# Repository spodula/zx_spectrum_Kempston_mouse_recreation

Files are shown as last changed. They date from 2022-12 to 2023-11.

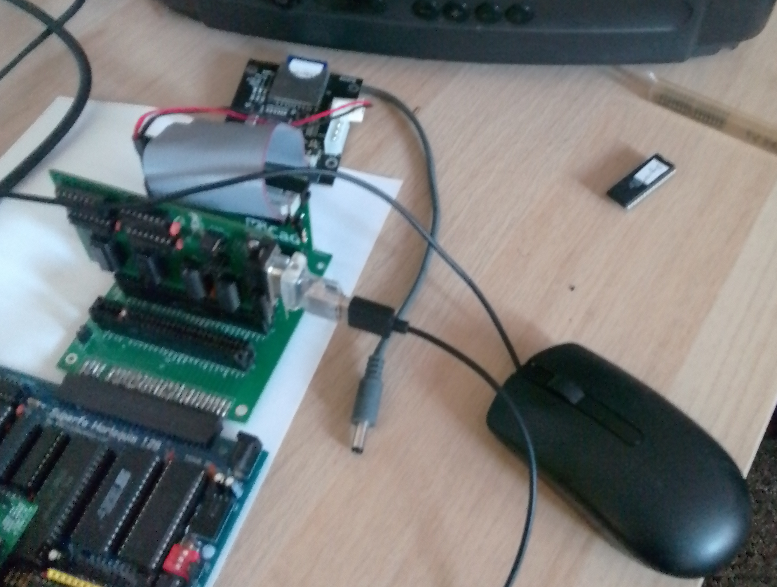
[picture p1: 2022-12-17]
mouse-board-in-use.jpg

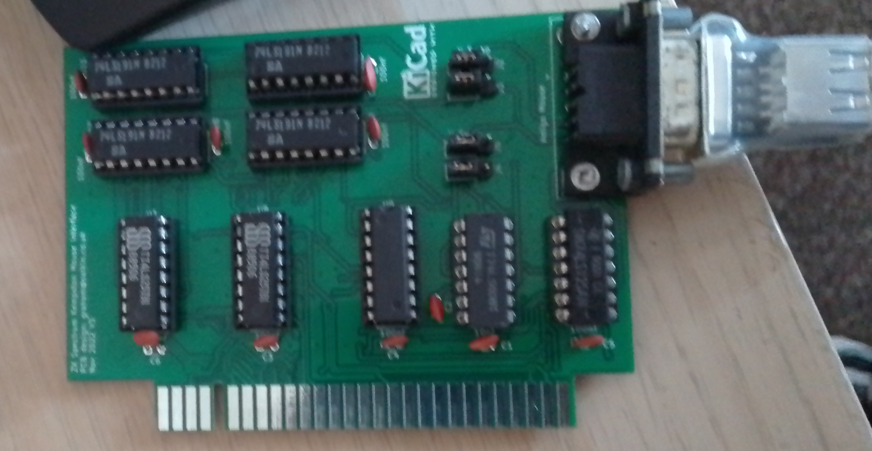
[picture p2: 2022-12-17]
mouse-board1.jpg

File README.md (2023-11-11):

# zx_spectrum_Kempston_mouse_recreation
This is a copy of the classic Kempston mouse interface re-designed to use Amiga mice.
it uses all the same components, just pinout of the mouse connector differs from the classic kempston mouse.
(So in the unlikely event you have an original kempston mouse, DO NOT plug it in)
I personally use an amiga Mouse adapter I got from Ebay with an old Dell Optical mouse. This seems to work fine. 

Gerbers files are complete, and you should just be able to zip them up and send them straight to your PCB manafacturer of your choice. 

All of this was done from the Schematics available at: 
Kio at https://k1.spdns.de/Vintage/Sinclair/82/Peripherals/Mouse%20Interfaces/Kempston%20Mouse%20Interface/
My additions are:
* support for 3 button mice
* Re-arrange pinout so its compatable with the Amiga mouse. 

BUGS!
-----
Minor bug, C1 should be next to C2, and C8 should be where C1 is for decoupling!
Fortunately, as the board is overly decoupled anyway (And frankly, its doubtful if U2 needs decoupling, as its only changes its logic states a few tens of times a second at most), this isnt really an issue, HOWEVER Do make sure you dont put a 100nf as C1. This could cause bad reads from the mouse. 

Parts required: 
---------------
* 74LS191 x4
* 74LS257 x2
* 74LS138
* 74LS00
* 74LS125
* 10nf capacitor x2
* 100nf capacitors x9
* PCB mount DB9 connector.
* Edge connector x1 (If required)

Note, the jumpers J2,3,4,5 are there because i wasnt sure of the X1/X2 Y1/Y2 order. 
Now i know, you can just jumper the squared pins off (technically Pins 2/3), so the next version probably wont have them. 
(look at the terrible photos in the folder)

No licence on this board, use it, manafacture it, sell it, fart in its general direction, have fun with it..
If you do modify it, be sure to credit Kio at the above URL.

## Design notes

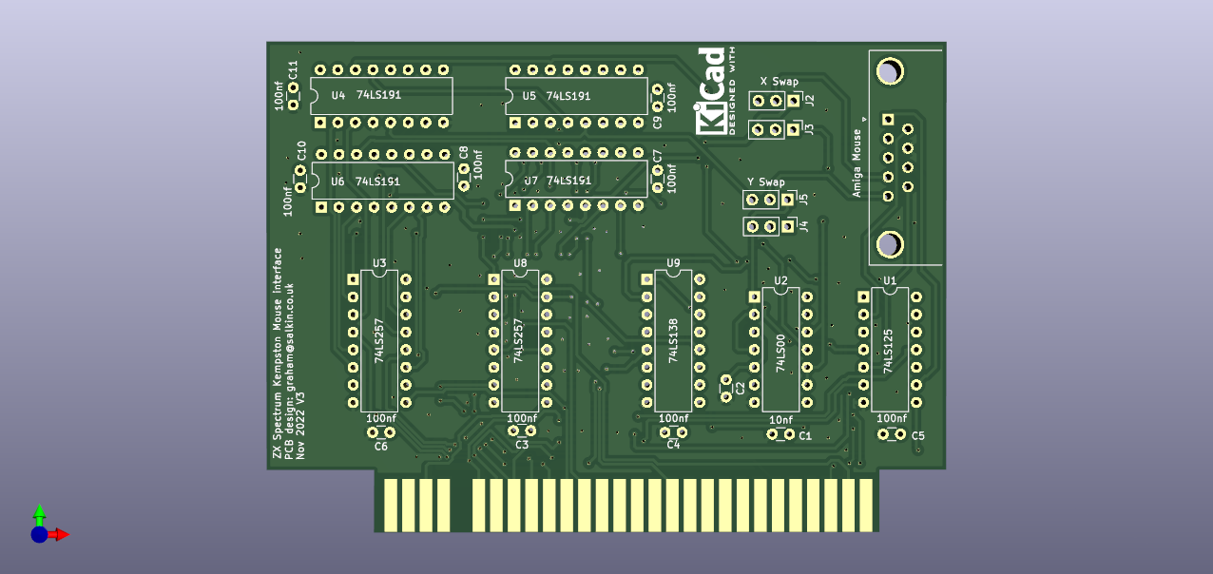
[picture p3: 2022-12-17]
Mouse_pcb_front.png

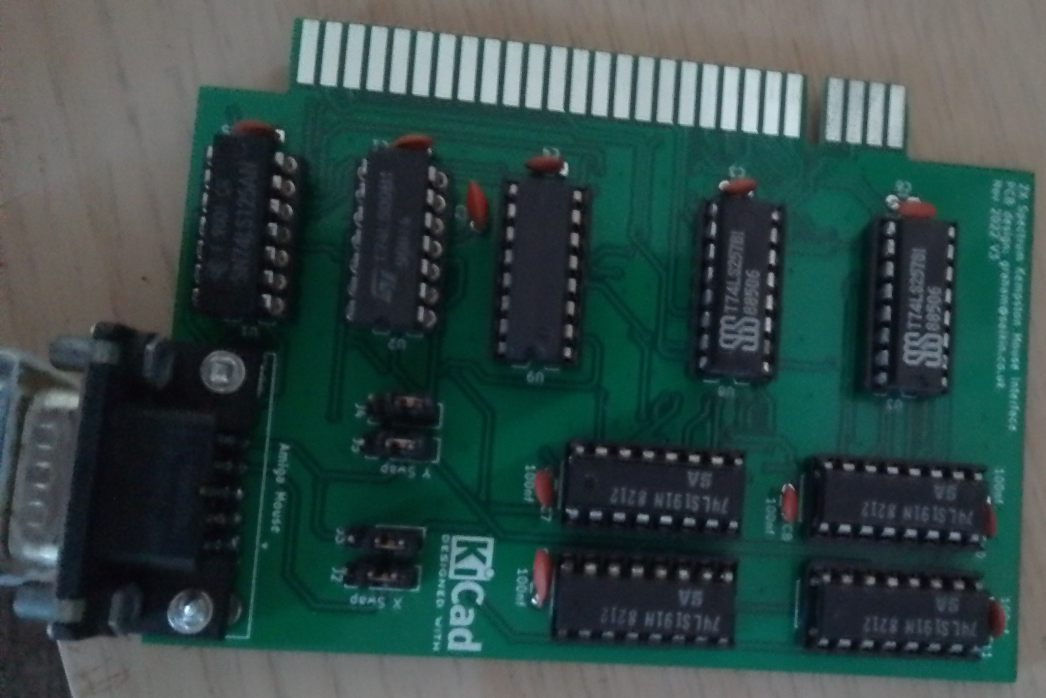
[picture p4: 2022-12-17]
mouse-board2.jpg

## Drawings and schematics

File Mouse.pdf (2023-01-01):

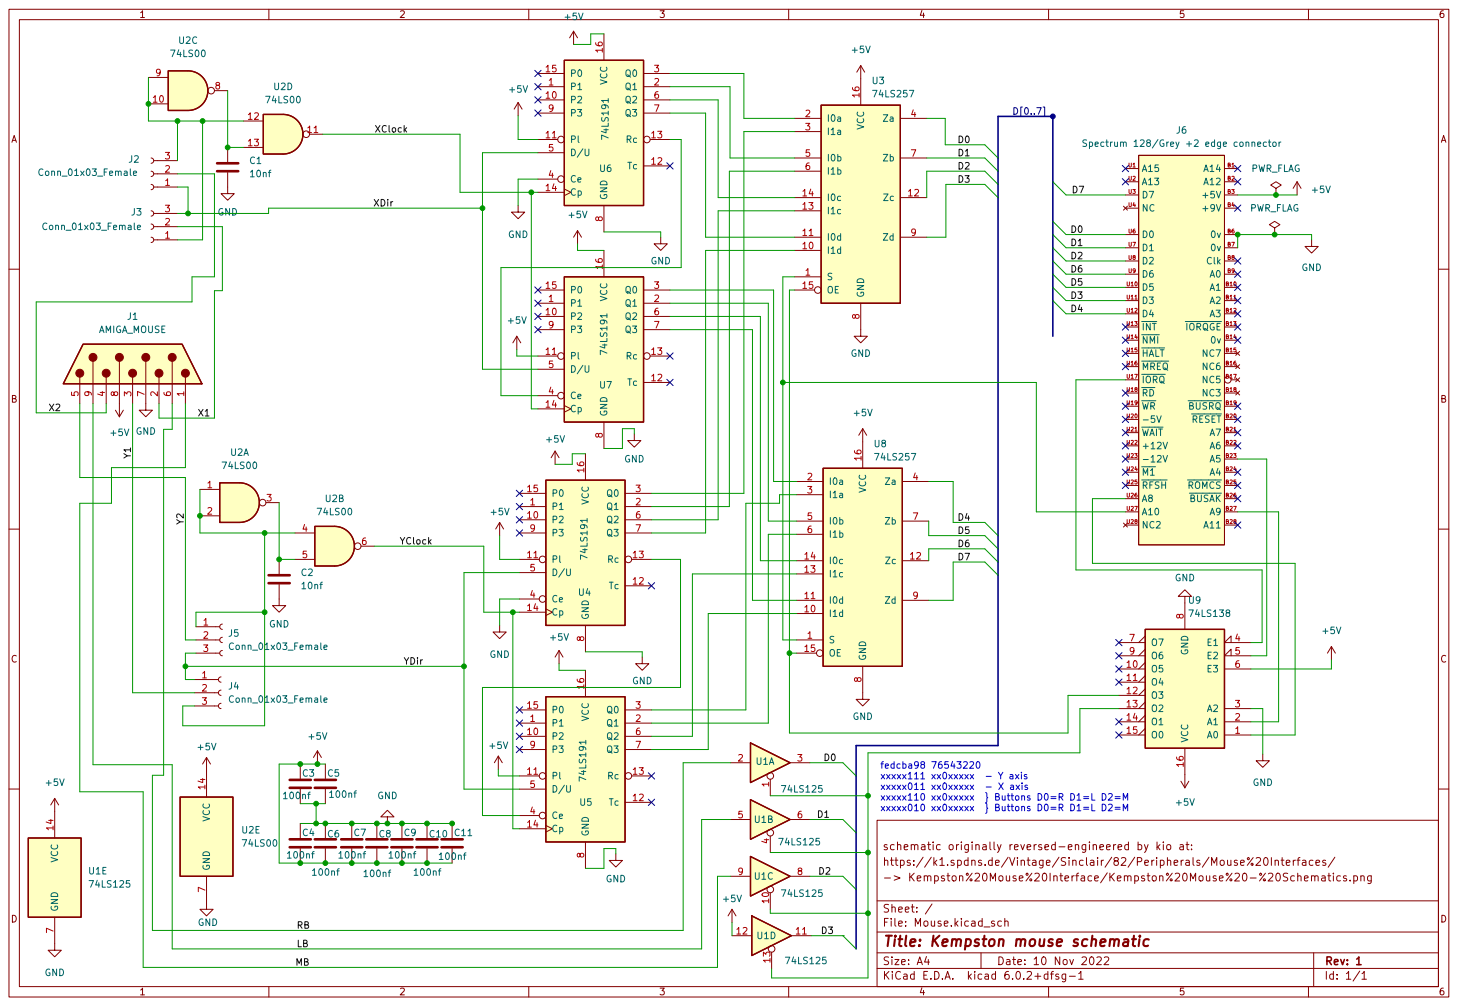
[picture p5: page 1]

8 P3 9 U774LS191 A14 B1 A1 B10 A2 B11 A3 B12 ~{IORQGE}B13 0v B14 NC7 B15 NC6 B16 NC5 B17 NC3 B18 ~{BUSRQ}B19 A12 B2 ~{RESET}B20 A7 B21 A6 B22 A5 B23 A4 B24 ~{ROMCS}B25 ~{BUSAK} B26 A9 B27 A11 B28 +5V B3 +9V B4 0v B6 0v B7 Clk B8 A0 B9 A15 U1 D5 U10 D3 U11 D4 U12 ~{INT} U13 ~{NMI} U14 ~{HALT} U15 ~{MREQ} U16 ~{IORQ} U17 ~{RD} U18 ~{WR} U19 A13 U2

8 P3 9 U474LS191 P1 1 P2 10 Pl 11 Tc 12 Rc 13 Cp 14 P0 15 VCC 16 Q1 2 Q0 3 Ce 4 D/U 5 Q2 6 Q3 7 GND

schematic originally reversed-engineered by kio at: +5V C8

https://k1.spdns.de/Vintage/Sinclair/82/Peripherals/Mouse%20Interfaces/
File: Mouse.kicad_sch Sheet: / -> Kempston%20Mouse%20Interface/Kempston%20Mouse%20-%20Schematics.png

Id: 1/1 Title: Kempston mouse schematic

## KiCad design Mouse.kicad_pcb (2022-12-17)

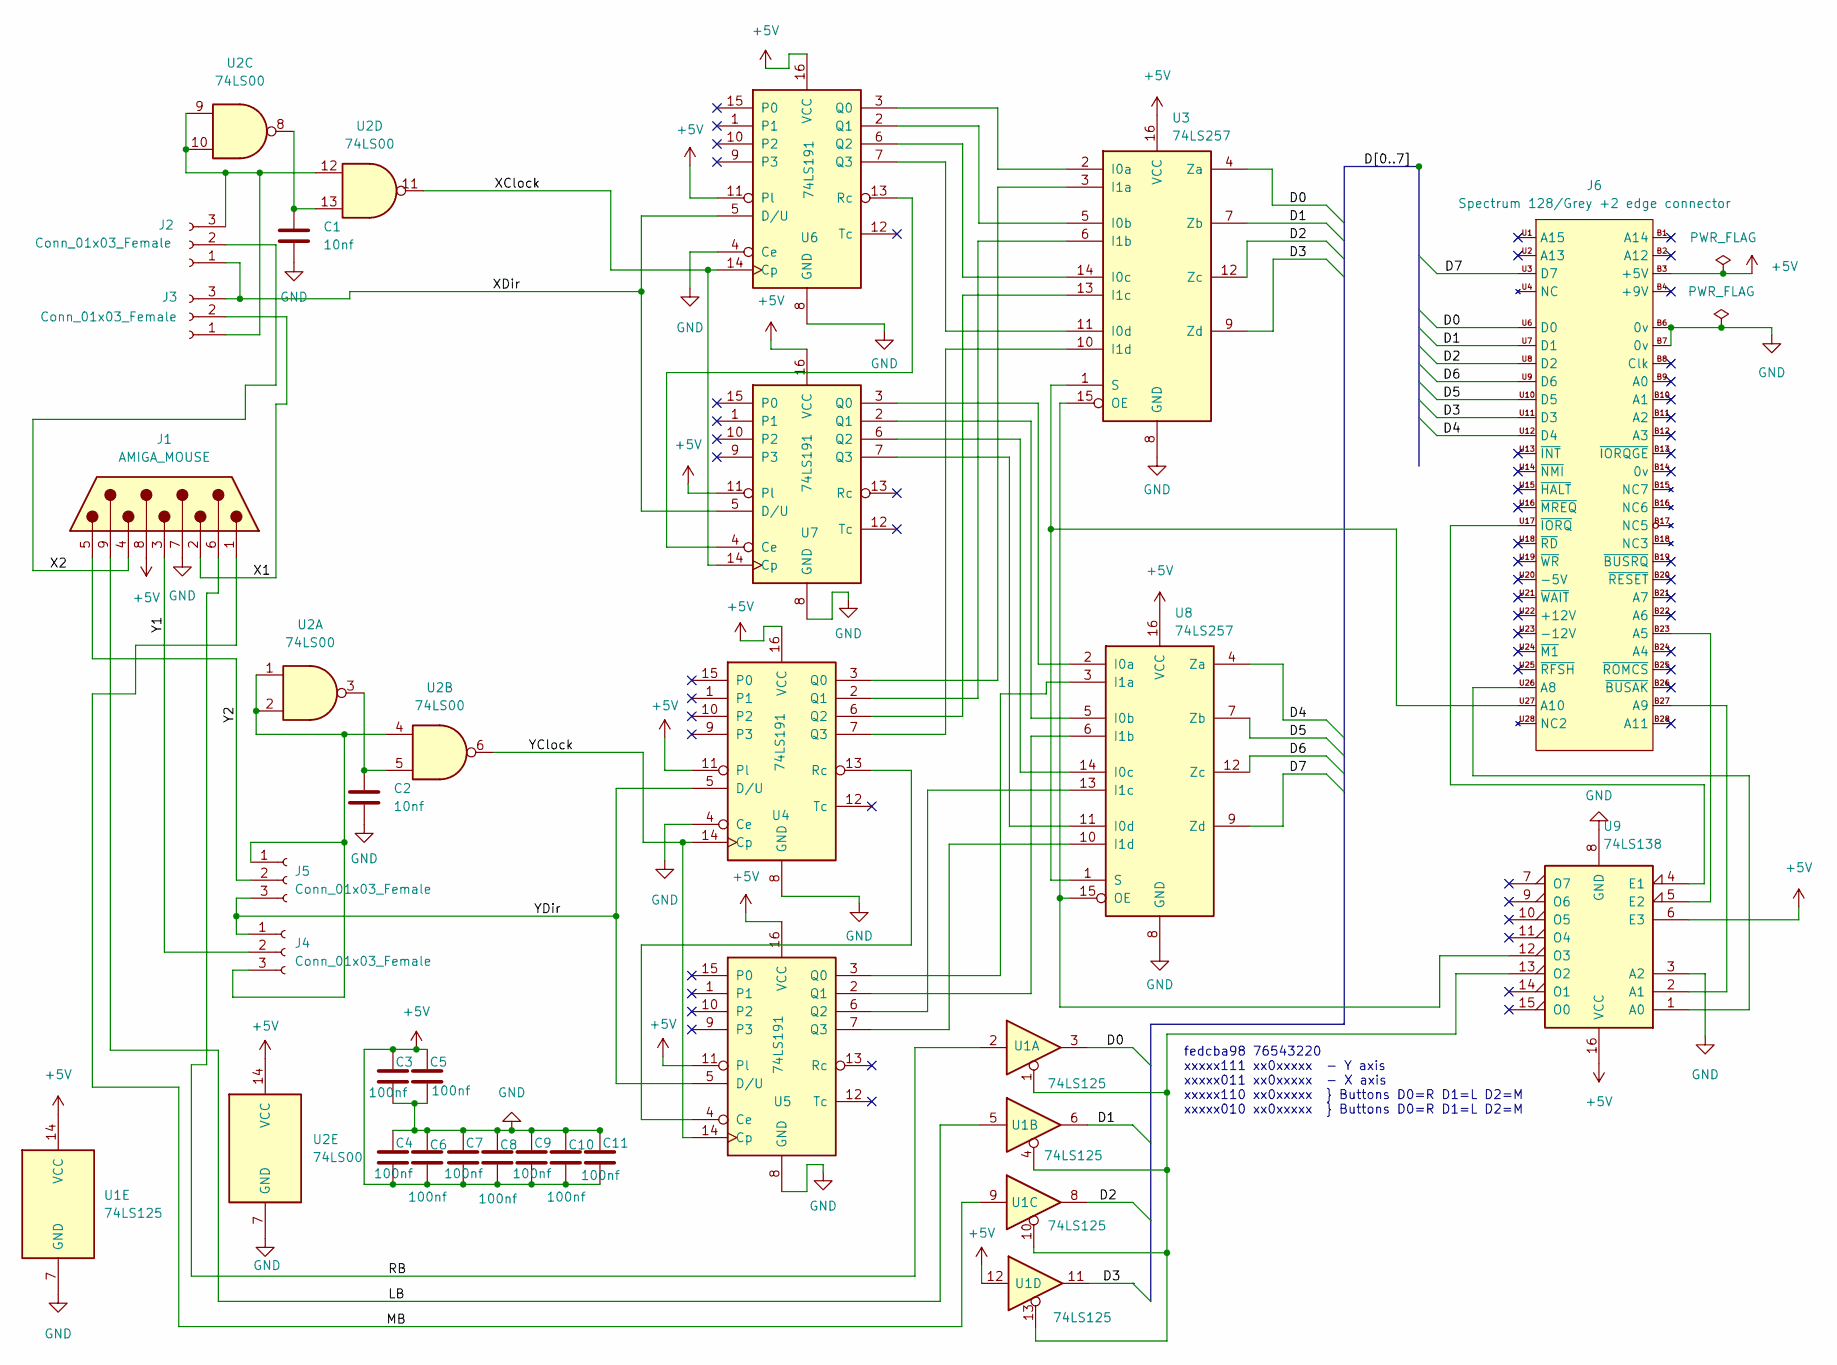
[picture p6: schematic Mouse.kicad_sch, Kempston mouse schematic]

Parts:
C1, C2: 10nf; C_Disc_D3.0mm_W1.6mm_P2.50mm
C3, C4, C5, C6, C7, C8, C9, C10, C11: 100nf; C_Disc_D3.0mm_W1.6mm_P2.50mm
J1: AMIGA_MOUSE; DSUB-9_Female_Horizontal_P2.77x2.84mm_EdgePinOffset4.94mm_H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
J2, J3, J4, J5: Conn_01x03_Female; PinHeader_1x03_P2.54mm_Vertical
J6: Spectrum 128/Grey +2 edge connector; Speccy_edge_External
U1: 74LS125; DIP-14_W7.62mm
U2: 74LS00; DIP-14_W7.62mm
U3, U8: 74LS257; DIP-16_W7.62mm
U4, U5, U6, U7: 74LS191; DIP-16_W7.62mm
U9: 74LS138; DIP-16_W7.62mm

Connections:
+5V: C3.1, C4.2, C5.1, C6.2, C7.2, C8.2, C9.2, C10.2, C11.2, J1.8, J6.B3 (+5V), U1.12, U1.14 (VCC), U2.14 (VCC), U3.16 (VCC), U4.11 (Pl), U4.16 (VCC), U5.11 (Pl), U5.16 (VCC), U6.11 (Pl), U6.16 (VCC), U7.11 (Pl), U7.16 (VCC), U8.16 (VCC), U9.6 (E3), U9.16 (VCC)
/D0: J6.U6 (D0), U1.3, U3.4 (Za)
/D1: J6.U7 (D1), U1.6, U3.7 (Zb)
/D2: J6.U8 (D2), U1.8, U3.12 (Zc)
/D3: J6.U11 (D3), U1.11, U3.9 (Zd)
/D4: J6.U12 (D4), U8.4 (Za)
/D5: J6.U10 (D5), U8.7 (Zb)
/D6: J6.U9 (D6), U8.12 (Zc)
/D7: J6.U3 (D7), U8.9 (Zd)
/LB: J1.9, U1.5
/MB: J1.1, U1.9
/RB: J1.6, U1.2
/X1: J1.2, J3.2
/X2: J1.4, J2.2
/XClock: U2.11, U6.14 (Cp), U7.14 (Cp)
/XDir: J2.1, J3.3, U6.5 (D/U), U7.5 (D/U)
/Y1: J1.3, J4.2
/Y2: J1.5, J5.2
/YClock: U2.6, U4.14 (Cp), U5.14 (Cp)
/YDir: J4.1, J5.3, U4.5 (D/U), U5.5 (D/U)
GND: C1.2, C2.2, C3.2, C4.1, C5.2, C6.1, C7.1, C8.1, C9.1, C10.1, C11.1, J1.7, J6.B6 (0v), J6.B7 (0v), U1.7 (GND), U2.7 (GND), U3.8 (GND), U4.4 (Ce), U4.8 (GND), U5.8 (GND), U6.4 (Ce), U6.8 (GND), U7.8 (GND), U8.8 (GND), U9.3 (A2), U9.8 (GND)
unnamed: C1.1, U2.8, U2.13
unnamed: C2.1, U2.3, U2.5
unnamed: J2.3, J3.1, U2.9, U2.10, U2.12
unnamed: J4.3, J5.1, U2.1, U2.2, U2.4
unnamed: J6.B23 (A5), U9.5 (E2)
unnamed: J6.B27 (A9), U9.2 (A1)
unnamed: J6.U17 (~IORQ), U9.4 (E1)
unnamed: J6.U26 (A8), U9.1 (A0)
unnamed: J6.U27 (A10), U3.1 (S), U8.1 (S)
unnamed: U1.1, U1.4, U1.10, U1.13, U9.13 (O2)
unnamed: U3.2 (I0a), U6.3 (Q0)
unnamed: U3.3 (I1a), U4.3 (Q0)
unnamed: U3.5 (I0b), U6.2 (Q1)
unnamed: U3.6 (I1b), U4.2 (Q1)
unnamed: U3.10 (I1d), U4.7 (Q3)
unnamed: U3.11 (I0d), U6.7 (Q3)
unnamed: U3.13 (I1c), U4.6 (Q2)
unnamed: U3.14 (I0c), U6.6 (Q2)
unnamed: U3.15 (OE), U8.15 (OE), U9.12 (O3)
unnamed: U4.13 (Rc), U5.4 (Ce)
unnamed: U5.2 (Q1), U8.6 (I1b)
unnamed: U5.3 (Q0), U8.3 (I1a)
unnamed: U5.6 (Q2), U8.13 (I1c)
unnamed: U5.7 (Q3), U8.10 (I1d)
unnamed: U6.13 (Rc), U7.4 (Ce)
unnamed: U7.2 (Q1), U8.5 (I0b)
unnamed: U7.3 (Q0), U8.2 (I0a)
unnamed: U7.6 (Q2), U8.14 (I0c)
unnamed: U7.7 (Q3), U8.11 (I0d)

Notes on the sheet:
fedcba98 76543220 xxxxx111 xx0xxxxx - Y axis xxxxx011 xx0xxxxx - X axis xxxxx110 xx0xxxxx } Buttons D0=R D1=L D2=M xxxxx010 xx0xxxxx } Buttons D0=R D1=L D2=M

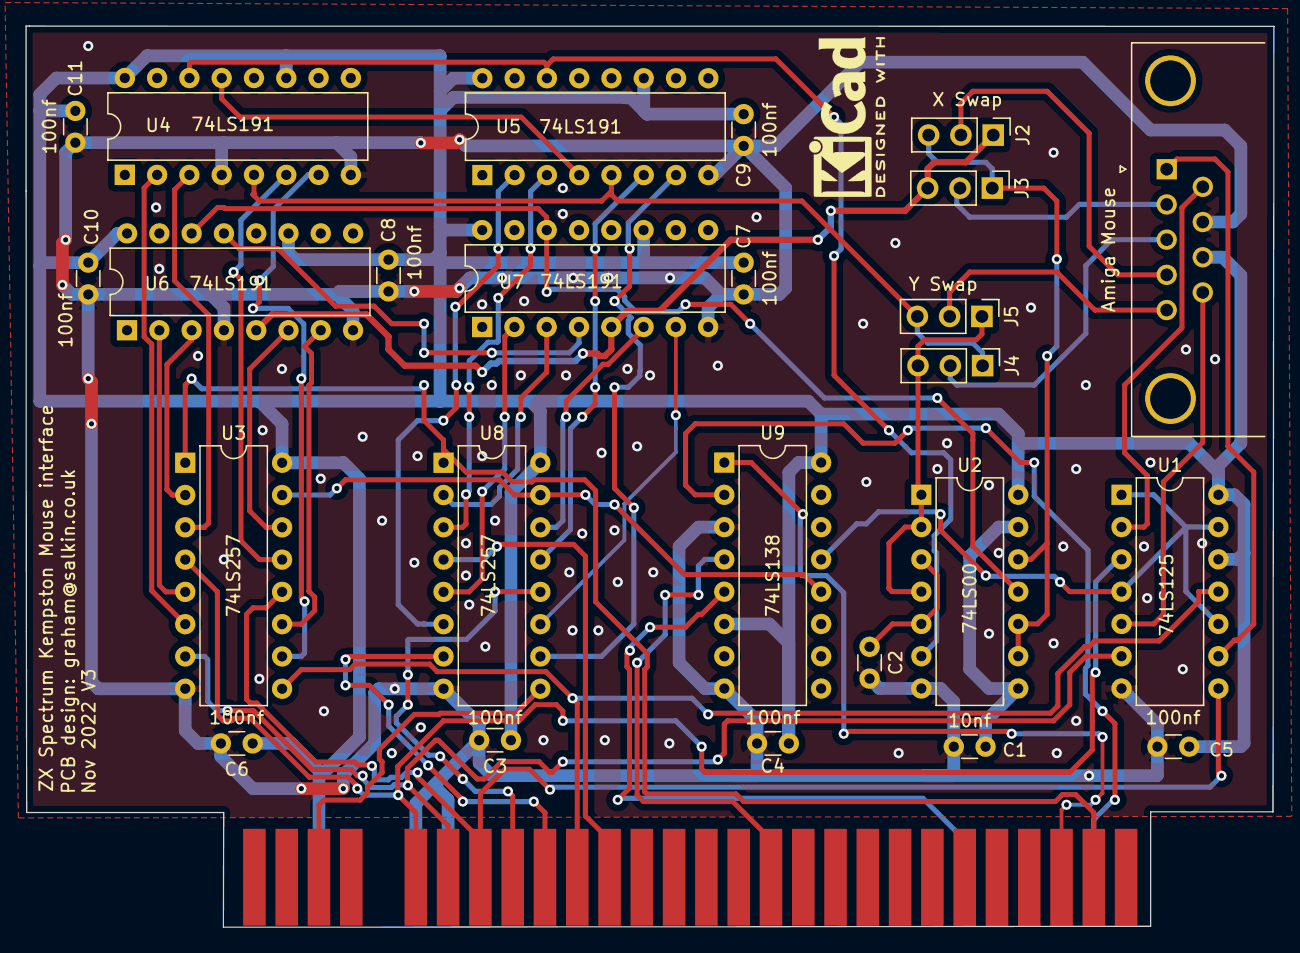
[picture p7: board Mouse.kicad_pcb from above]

Board: 2 copper layers, 98.2 x 70.9 mm, 26 parts (0 on the bottom side), 50 nets.

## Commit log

2022-12-17 Initial login
    [Mouse-B_Cu.gbr, Mouse-B_Mask.gbr, Mouse-B_Paste.gbr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]
2023-01-01 Added schematic in readable format
